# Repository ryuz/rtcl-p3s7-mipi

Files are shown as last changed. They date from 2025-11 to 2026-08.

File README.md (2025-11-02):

English version: [README_en.md](README_en.md)

# グローバルシャッターMIPI高速度カメラ(PYTHON300 + Spartan7)

## 概要

[こちら](https://rtc-lab.com/products/rtcl-cam-p3s7-mipi/)で紹介しておりますグローバルシャッターMIPI高速度カメラの KiCAD による設計データです。

オンセミコンダクター社 [PYTHON300イメージセンサー](https://www.onsemi.jp/products/sensors/image-sensors/python300) と AMD(Xilinx) の [Spartan7](https://www.amd.com/ja/products/adaptive-socs-and-fpgas/fpga/spartan-7.html) FPGA を用いた研究開発向けの小型のカメラモジュールです。

データシート上は VGA サイズながら 815fps の高速度撮影が可能と記載されているセンサーを利用しており、当方では [KV260](https://www.amd.com/ja/products/system-on-modules/kria/k26/kv260-vision-starter-kit.html) と [Zybo Z7](https://digilent.com/shop/zybo-z7-zynq-7000-arm-fpga-soc-development-board/) に接続して 320x320 サイズで 1000fps 撮像が出来ております。

カメラ外観写真

撮影動画なども[こちら](https://rtc-lab.com/products/rtcl-cam-p3s7-mipi/)で紹介しております。

## 回路図

回路図は以下です。

- [イメージセンサー子基板](sensor_python300/sensor_python300.pdf)
- [FPGA親基板](mipi_spartan7/mipi_spartan7.pdf)

## 基板販売

当方で製造したものを[BOOTH](https://rtc-lab.booth.pm/)にて販売中です。

- [モノクロ版](https://rtc-lab.booth.pm/items/7427869)
- [カラー版](https://rtc-lab.booth.pm/items/7428802)

## 関連ソフトウェア

現時点では、KV260 に独自仕様でデータを送るプロジェクトがあります。

- [Spartan-7 のデザイン](https://github.com/ryuz/rtcl-designs/tree/main/projects/rtcl_p3s7_mipi/rtcl_p3s7_mipi)
- [KV260 の デザイン](https://github.com/ryuz/rtcl-designs/tree/main/projects/kv260/kv260_rtcl_p3s7_hs)
- [ZYBO の デザイン](https://github.com/ryuz/rtcl-designs/tree/main/projects/zybo_z7/zybo_z7_rtcl_p3s7_hs)

## リポジトリ構成

| ディレクトリ |  説明 |
|:---|:---|
| mipi_spartan7 | Spartan7 FPGA の載った親基板のプロジェクト |
| sensor_python300 | PYTHON300 イメージセンサーの載った子基板のプロジェクト |
| sensor_mipi | 親子基板を共取り製造用に結合したプロジェクト |

## 免責事項

本設計データは、研究開発用の試作実験に用するものであり、利用に際して発生した如何なる損害も作者は補償いたしませんので予めご了承ください。

## ライセンス(License)

本設計データは、[クリエイティブ・コモンズ 表示-非営利 4.0 国際 ライセンス](https://creativecommons.org/licenses/by-nc/4.0/deed.ja)の下で提供されています。

製造した本基板の無断での販売や配布を行わない限りは、趣味や研究開発用途でご自由にお使いいただく事が出来ます。

また、商用に製造販売を希望される場合は、別途ライセンス契約を作者までご相談ください。[お問い合わせフォーム](https://rtc-lab.com/contact/)などからお問い合わせ頂けます。

## 作者情報

渕上 竜司(Ryuji Fuchikami)
[リアルタイムコンピューティング研究所](https://rtc-lab.com/)

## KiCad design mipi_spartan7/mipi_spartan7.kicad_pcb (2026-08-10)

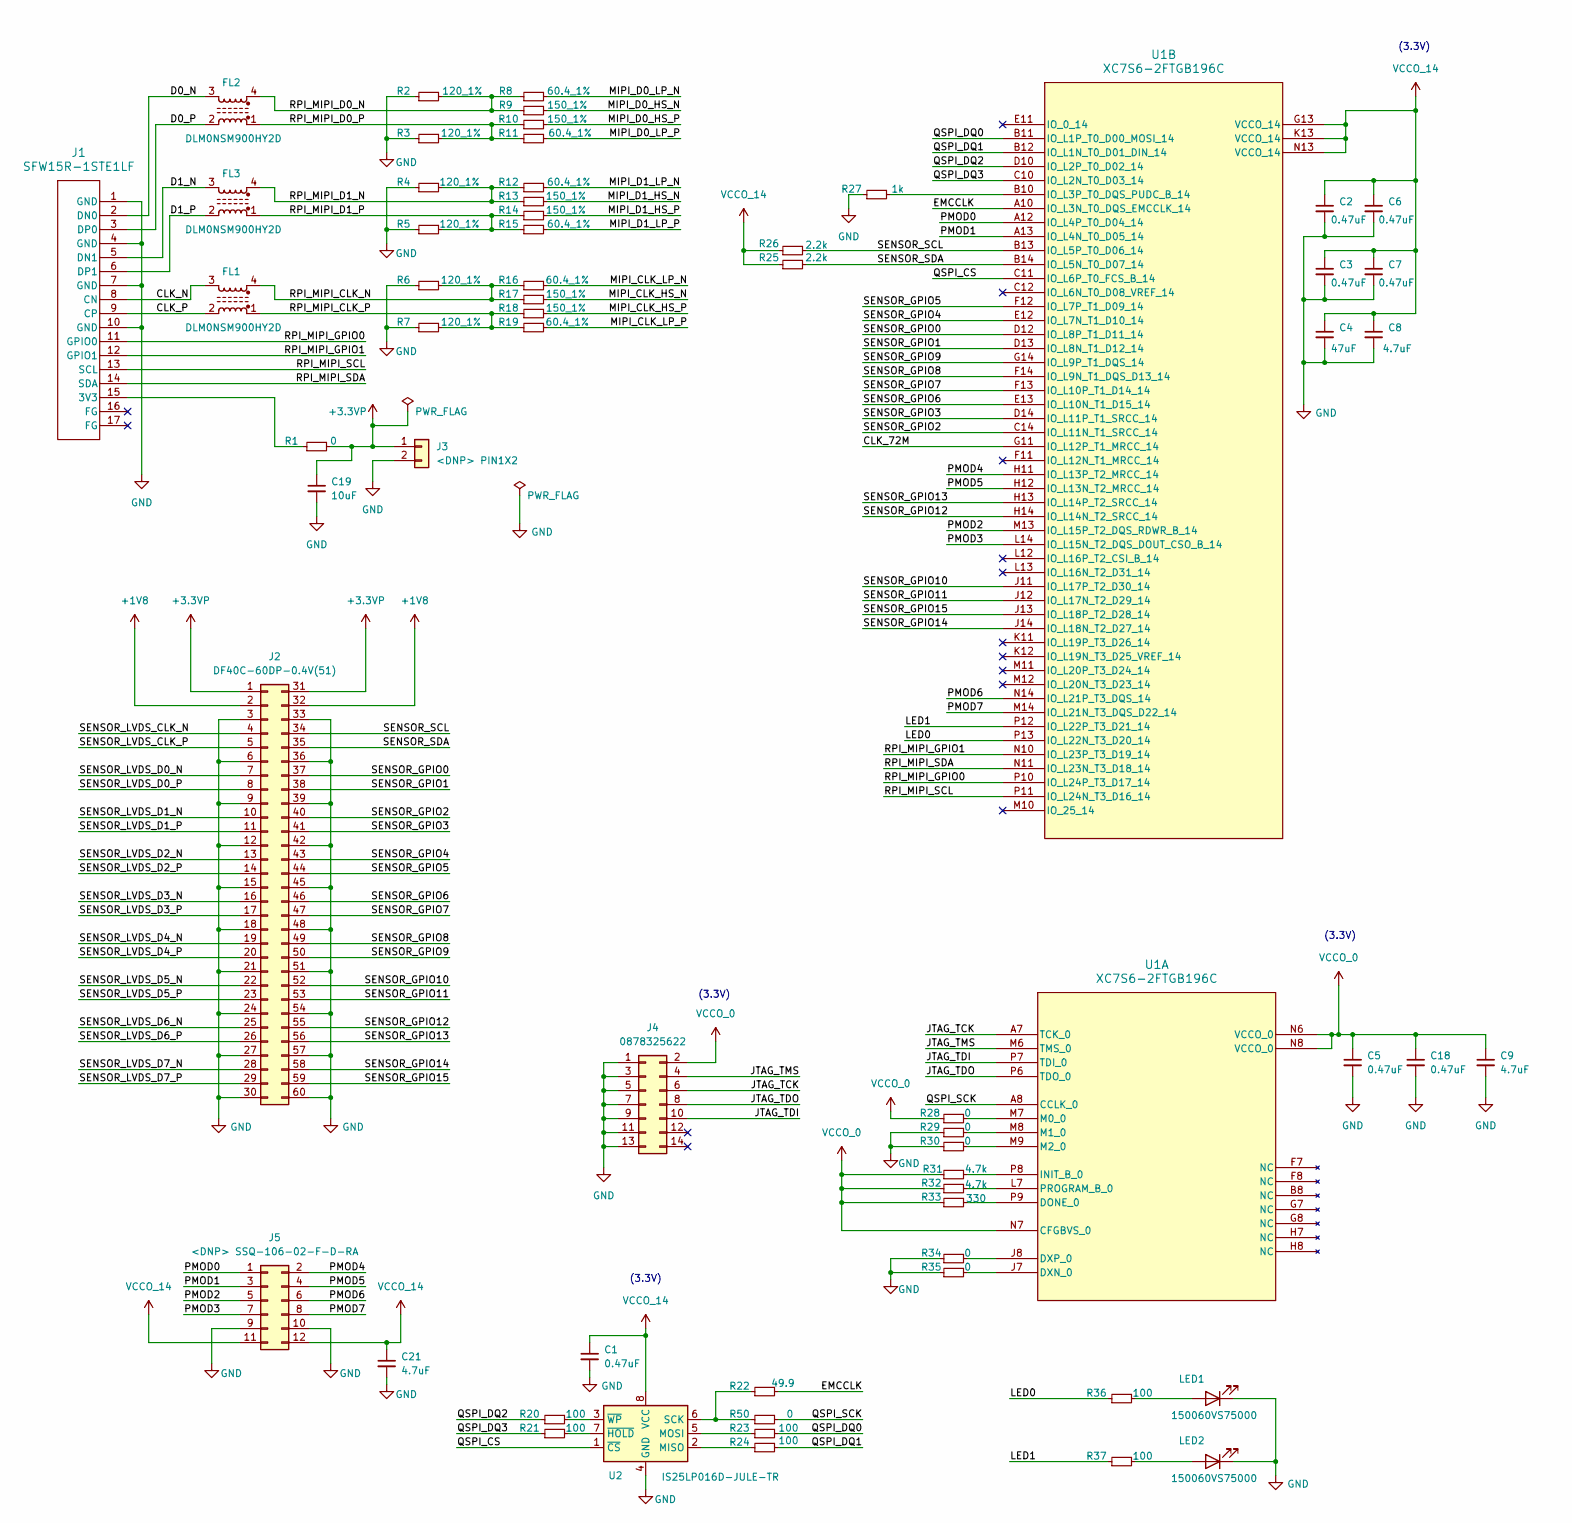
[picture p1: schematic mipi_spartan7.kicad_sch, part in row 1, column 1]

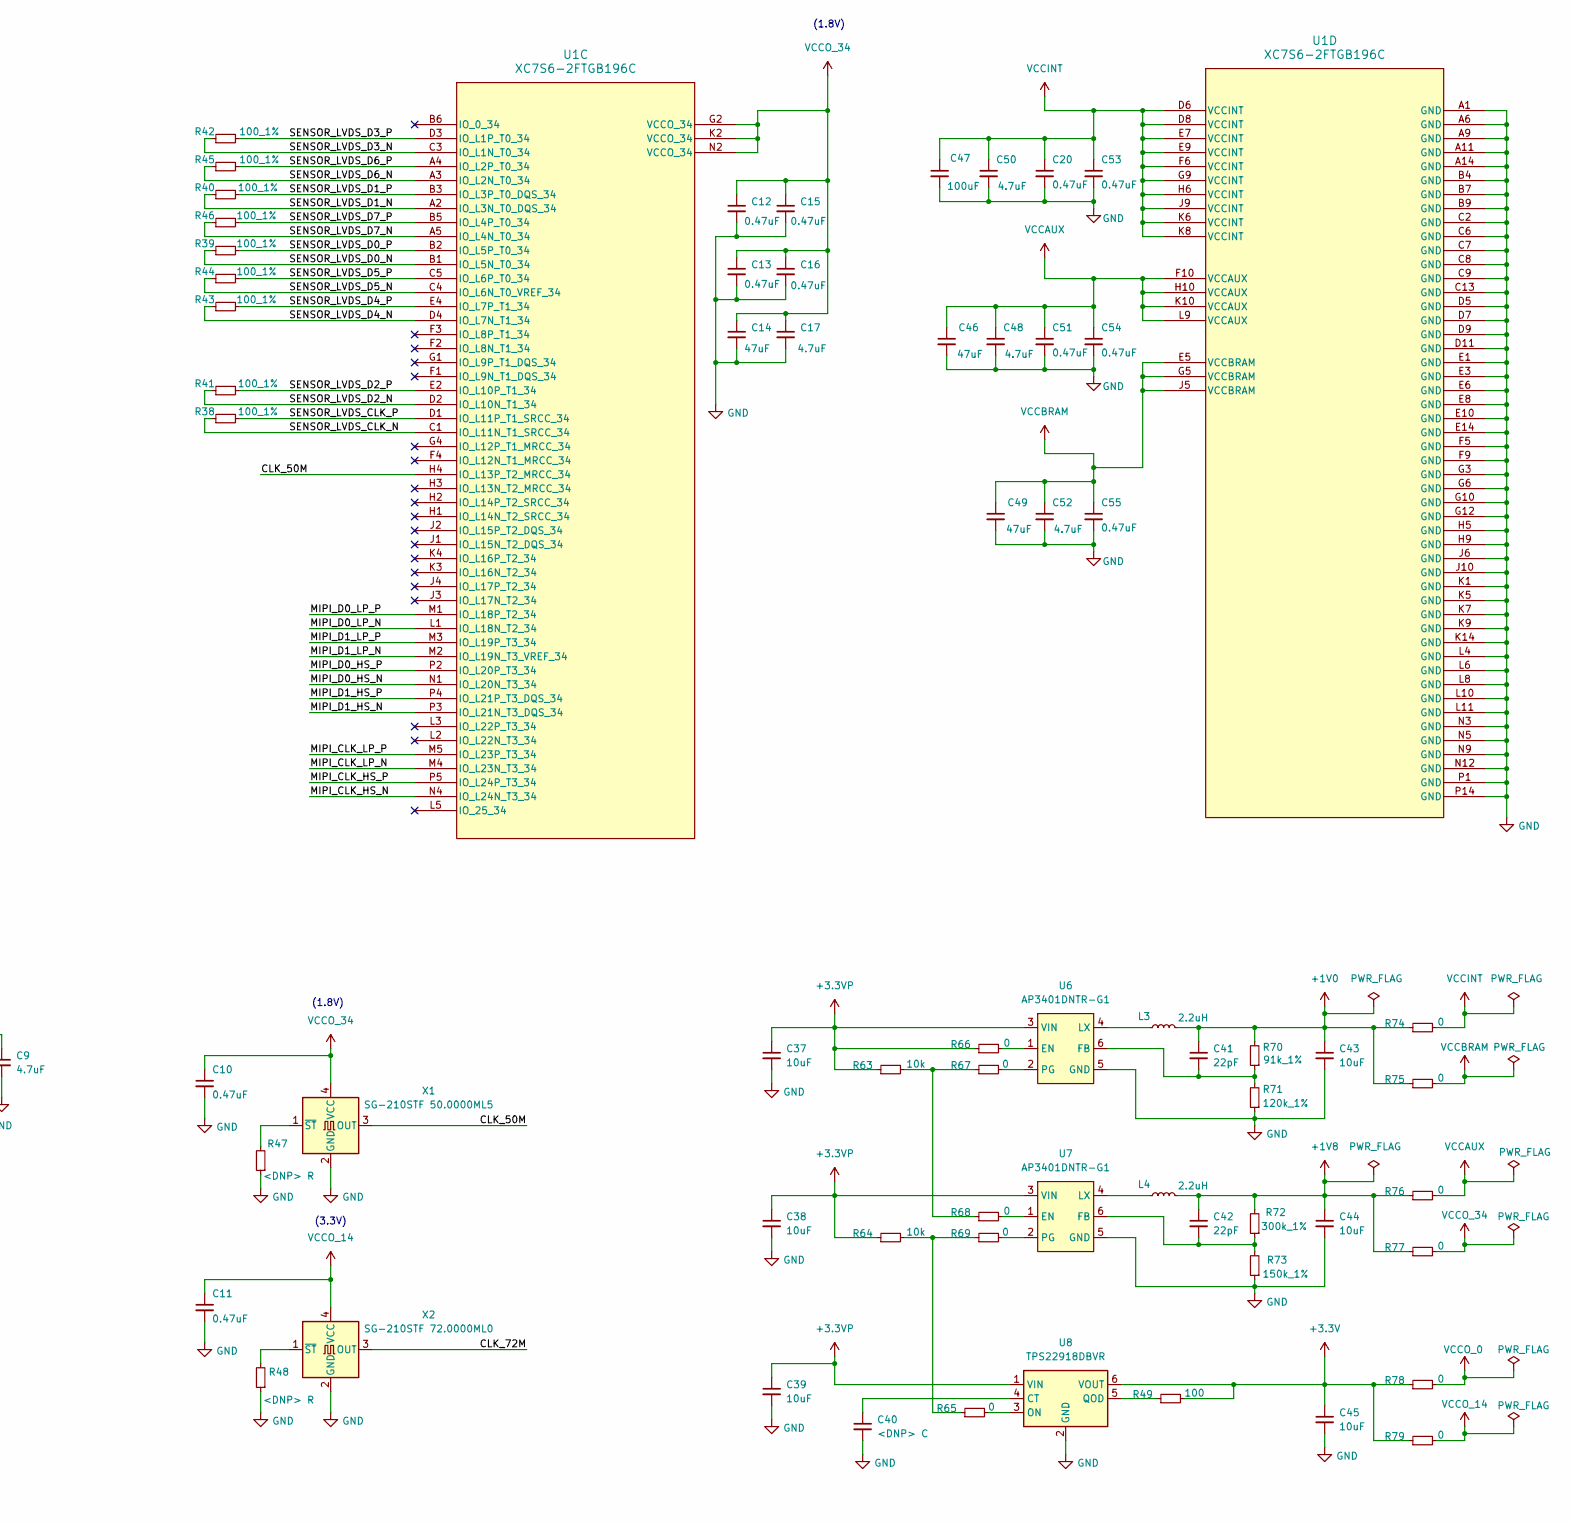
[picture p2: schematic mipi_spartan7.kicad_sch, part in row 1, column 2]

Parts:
C1, C2, C3, C5, C6, C7, C10, C11, C12, C13, C15, C16, C18, C20, C51, C53, C54, C55: 0.47uF; C_0402_1005Metric
C4, C14, C46, C49: 47uF; C_0603_1608Metric
C8, C9, C17, C21, C48, C50, C52: 4.7uF; C_0402_1005Metric
C19, C37, C38, C39, C43, C44, C45: 10uF; C_0603_1608Metric
C40: <DNP> C; L_0402_1005Metric
C41, C42: 22pF; L_0402_1005Metric
C47: 100uF; C_1206_3216Metric
FL1, FL2, FL3: DLM0NSM900HY2D; JLC C1857796
J1: SFW15R-1STE1LF
J2: DF40C-60DP-0.4V(51); DF40C-60DP-0.4V51
J3: <DNP> PIN1X2; PH_01x02_2.54mm_NoSilk
J4: 0878325622; 878325622; JLC C17275712
J5: <DNP> SSQ-106-02-F-D-RA; PH_02x06_2.54mm
L3, L4: 2.2uH; L_1008_2520Metric; JLC C576403
LED1, LED2: 150060VS75000; LED_0603_1608Metric
R1, R28, R29, R30, R34, R35, R50, R65, R66, R67, R68, R69, R74, R75, R76, R77, R78, R79: 0; R_0402_1005Metric
R2, R3, R4, R5, R6, R7: 120_1%; R_0402_1005Metric
R8, R11, R12, R15, R16, R19: 60.4_1%; R_0402_1005Metric
R9, R10, R13, R14, R17, R18: 150_1%; R_0402_1005Metric
R20, R21, R23, R24, R36, R37, R49: 100; R_0402_1005Metric
R22: 49.9; R_0402_1005Metric
R25, R26: 2.2k; R_0402_1005Metric
R27: 1k; R_0402_1005Metric
R31, R32: 4.7k; R_0402_1005Metric
R33: 330; R_0402_1005Metric
R38, R39, R40, R41, R42, R43, R44, R45, R46: 100_1%; R_0402_1005Metric
R47, R48: <DNP> R; R_0402_1005Metric
R63, R64: 10k; R_0402_1005Metric
R70: 91k_1%; R_0402_1005Metric
R71: 120k_1%; R_0402_1005Metric
R72: 300k_1%; R_0402_1005Metric
R73: 150k_1%; R_0402_1005Metric
U1: XC7S6-2FTGB196C; FTGB196; JLC C1521961
U2: IS25LP016D-JULE-TR; JLC C2063555
U6, U7: AP3401DNTR-G1; Diodes_UDFN2020-6_Type-J; JLC C507877
U8: TPS22918DBVR; SOT-23-6; JLC C131941
X1: SG-210STF 50.0000ML5; SG-210STF; JLC C17669095
X2: SG-210STF 72.0000ML0; SG-210STF; JLC C17270014

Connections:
+1V0: C41.1, C43.1, L3.2, R70.2, R74.1, R75.1
+1V8: C42.1, C44.1, J2.2, J2.32, L4.2, R72.2, R76.1, R77.1
+3.3V: C45.1, R49.2, R78.1, R79.1, U8.6 (VOUT)
+3.3VP: C19.1, C37.1, C38.1, C39.1, J2.1, J2.31, J3.1, R1.2, R63.1, R64.1, R66.1, U6.3 (VIN), U7.3 (VIN), U8.1 (VIN)
/CLK_50M: U1.H4 (IO_L13P_T2_MRCC_34), X1.3 (OUT)
/CLK_72M: U1.G11 (IO_L12P_T1_MRCC_14), X2.3 (OUT)
/CLK_N: FL1.3, J1.8 (CN)
/CLK_P: FL1.2, J1.9 (CP)
/D0_N: FL2.3, J1.2 (DN0)
/D0_P: FL2.2, J1.3 (DP0)
/D1_N: FL3.3, J1.5 (DN1)
/D1_P: FL3.2, J1.6 (DP1)
/EMCCLK: R22.2, U1.A10 (IO_L3N_T0_DQS_EMCCLK_14)
/JTAG_TCK: J4.6, U1.A7 (TCK_0)
/JTAG_TDI: J4.10, U1.P7 (TDI_0)
/JTAG_TDO: J4.8, U1.P6 (TDO_0)
/JTAG_TMS: J4.4, U1.M6 (TMS_0)
/LED0: R36.1, U1.P13 (IO_L22N_T3_D20_14)
/LED1: R37.1, U1.P12 (IO_L22P_T3_D21_14)
/MIPI_CLK_HS_N: R17.2, U1.N4 (IO_L24N_T3_34)
/MIPI_CLK_HS_P: R18.2, U1.P5 (IO_L24P_T3_34)
/MIPI_CLK_LP_N: R16.2, U1.M4 (IO_L23N_T3_34)
/MIPI_CLK_LP_P: R19.2, U1.M5 (IO_L23P_T3_34)
/MIPI_D0_HS_N: R9.2, U1.N1 (IO_L20N_T3_34)
/MIPI_D0_HS_P: R10.2, U1.P2 (IO_L20P_T3_34)
/MIPI_D0_LP_N: R8.2, U1.L1 (IO_L18N_T2_34)
/MIPI_D0_LP_P: R11.2, U1.M1 (IO_L18P_T2_34)
/MIPI_D1_HS_N: R13.2, U1.P3 (IO_L21N_T3_DQS_34)
/MIPI_D1_HS_P: R14.2, U1.P4 (IO_L21P_T3_DQS_34)
/MIPI_D1_LP_N: R12.2, U1.M2 (IO_L19N_T3_VREF_34)
/MIPI_D1_LP_P: R15.2, U1.M3 (IO_L19P_T3_34)
/PMOD0: J5.1, U1.A12 (IO_L4P_T0_D04_14)
/PMOD1: J5.3, U1.A13 (IO_L4N_T0_D05_14)
/PMOD2: J5.5, U1.M13 (IO_L15P_T2_DQS_RDWR_B_14)
/PMOD3: J5.7, U1.L14 (IO_L15N_T2_DQS_DOUT_CSO_B_14)
/PMOD4: J5.2, U1.H11 (IO_L13P_T2_MRCC_14)
/PMOD5: J5.4, U1.H12 (IO_L13N_T2_MRCC_14)
/PMOD6: J5.6, U1.N14 (IO_L21P_T3_DQS_14)
/PMOD7: J5.8, U1.M14 (IO_L21N_T3_DQS_D22_14)
/QSPI_CS: U1.C11 (IO_L6P_T0_FCS_B_14), U2.1 (~CS)
/QSPI_DQ0: R23.2, U1.B11 (IO_L1P_T0_D00_MOSI_14)
/QSPI_DQ1: R24.2, U1.B12 (IO_L1N_T0_D01_DIN_14)
/QSPI_DQ2: R20.1, U1.D10 (IO_L2P_T0_D02_14)
/QSPI_DQ3: R21.1, U1.C10 (IO_L2N_T0_D03_14)
/QSPI_SCK: R50.2, U1.A8 (CCLK_0)
/RPI_MIPI_CLK_N: FL1.4, R6.2, R16.1, R17.1
/RPI_MIPI_CLK_P: FL1.1, R7.2, R18.1, R19.1
/RPI_MIPI_D0_N: FL2.4, R2.2, R8.1, R9.1
/RPI_MIPI_D0_P: FL2.1, R3.2, R10.1, R11.1
/RPI_MIPI_D1_N: FL3.4, R4.2, R12.1, R13.1
/RPI_MIPI_D1_P: FL3.1, R5.2, R14.1, R15.1
/RPI_MIPI_GPIO0: J1.11 (GPIO0), U1.P10 (IO_L24P_T3_D17_14)
/RPI_MIPI_GPIO1: J1.12 (GPIO1), U1.N10 (IO_L23P_T3_D19_14)
/RPI_MIPI_SCL: J1.13 (SCL), U1.P11 (IO_L24N_T3_D16_14)
/RPI_MIPI_SDA: J1.14 (SDA), U1.N11 (IO_L23N_T3_D18_14)
/SENSOR_GPIO0: J2.37, U1.D12 (IO_L8P_T1_D11_14)
/SENSOR_GPIO1: J2.38, U1.D13 (IO_L8N_T1_D12_14)
/SENSOR_GPIO2: J2.40, U1.C14 (IO_L11N_T1_SRCC_14)
/SENSOR_GPIO3: J2.41, U1.D14 (IO_L11P_T1_SRCC_14)
/SENSOR_GPIO4: J2.43, U1.E12 (IO_L7N_T1_D10_14)
/SENSOR_GPIO5: J2.44, U1.F12 (IO_L7P_T1_D09_14)
/SENSOR_GPIO6: J2.46, U1.E13 (IO_L10N_T1_D15_14)
/SENSOR_GPIO7: J2.47, U1.F13 (IO_L10P_T1_D14_14)
/SENSOR_GPIO8: J2.49, U1.F14 (IO_L9N_T1_DQS_D13_14)
/SENSOR_GPIO9: J2.50, U1.G14 (IO_L9P_T1_DQS_14)
/SENSOR_GPIO10: J2.52, U1.J11 (IO_L17P_T2_D30_14)
/SENSOR_GPIO11: J2.53, U1.J12 (IO_L17N_T2_D29_14)
/SENSOR_GPIO12: J2.55, U1.H14 (IO_L14N_T2_SRCC_14)
/SENSOR_GPIO13: J2.56, U1.H13 (IO_L14P_T2_SRCC_14)
/SENSOR_GPIO14: J2.58, U1.J14 (IO_L18N_T2_D27_14)
/SENSOR_GPIO15: J2.59, U1.J13 (IO_L18P_T2_D28_14)
/SENSOR_LVDS_CLK_N: J2.4, R38.1, U1.C1 (IO_L11N_T1_SRCC_34)
/SENSOR_LVDS_CLK_P: J2.5, R38.2, U1.D1 (IO_L11P_T1_SRCC_34)
/SENSOR_LVDS_D0_N: J2.7, R39.1, U1.B1 (IO_L5N_T0_34)
/SENSOR_LVDS_D0_P: J2.8, R39.2, U1.B2 (IO_L5P_T0_34)
/SENSOR_LVDS_D1_N: J2.10, R40.1, U1.A2 (IO_L3N_T0_DQS_34)
/SENSOR_LVDS_D1_P: J2.11, R40.2, U1.B3 (IO_L3P_T0_DQS_34)
/SENSOR_LVDS_D2_N: J2.13, R41.1, U1.D2 (IO_L10N_T1_34)
/SENSOR_LVDS_D2_P: J2.14, R41.2, U1.E2 (IO_L10P_T1_34)
/SENSOR_LVDS_D3_N: J2.16, R42.1, U1.C3 (IO_L1N_T0_34)
/SENSOR_LVDS_D3_P: J2.17, R42.2, U1.D3 (IO_L1P_T0_34)
/SENSOR_LVDS_D4_N: J2.19, R43.1, U1.D4 (IO_L7N_T1_34)
/SENSOR_LVDS_D4_P: J2.20, R43.2, U1.E4 (IO_L7P_T1_34)
/SENSOR_LVDS_D5_N: J2.22, R44.1, U1.C4 (IO_L6N_T0_VREF_34)
/SENSOR_LVDS_D5_P: J2.23, R44.2, U1.C5 (IO_L6P_T0_34)
/SENSOR_LVDS_D6_N: J2.25, R45.1, U1.A3 (IO_L2N_T0_34)
/SENSOR_LVDS_D6_P: J2.26, R45.2, U1.A4 (IO_L2P_T0_34)
/SENSOR_LVDS_D7_N: J2.28, R46.1, U1.A5 (IO_L4N_T0_34)
/SENSOR_LVDS_D7_P: J2.29, R46.2, U1.B5 (IO_L4P_T0_34)
/SENSOR_SCL: J2.34, R26.2, U1.B13 (IO_L5P_T0_D06_14)
/SENSOR_SDA: J2.35, R25.2, U1.B14 (IO_L5N_T0_D07_14)
GND: C1.2, C2.2, C3.2, C4.2, C5.2, C6.2, C7.2, C8.2, C9.2, C10.2, C11.2, C12.2, C13.2, C14.2, C15.2, C16.2, C17.2, C18.2, C19.2, C20.2, C21.2, C37.2, C38.2, C39.2, C40.2, C43.2, C44.2, C45.2, C46.2, C47.2, C48.2, C49.2, C50.2, C51.2, C52.2, C53.2, C54.2, C55.2, J1.1 (GND), J1.4 (GND), J1.7 (GND), J1.10 (GND), J2.3, J2.6, J2.9, J2.12, J2.15, J2.18, J2.21, J2.24, J2.27, J2.30, J2.33, J2.36, J2.39, J2.42, J2.45, J2.48, J2.51, J2.54, J2.57, J2.60, J3.2, J4.1, J4.3, J4.5, J4.7, J4.9, J4.11, J4.13, J5.9, J5.10, LED1.1 (K), LED2.1 (K), R2.1, R3.1, R4.1, R5.1, R6.1, R7.1, R27.1, R29.1, R30.1, R34.1, R35.1, R47.1, R48.1, R71.1, R73.1, U1.A1 (GND), U1.A6 (GND), U1.A9 (GND), U1.A11 (GND), U1.A14 (GND), U1.B4 (GND), U1.B7 (GND), U1.B9 (GND), U1.C2 (GND), U1.C6 (GND), U1.C7 (GND), U1.C8 (GND), U1.C9 (GND), U1.C13 (GND), U1.D5 (GND), U1.D7 (GND), U1.D9 (GND), U1.D11 (GND), U1.E1 (GND), U1.E3 (GND), U1.E6 (GND), U1.E8 (GND), U1.E10 (GND), U1.E14 (GND), U1.F5 (GND), U1.F9 (GND), U1.G3 (GND), U1.G6 (GND), U1.G10 (GND), U1.G12 (GND), U1.H5 (GND), U1.H9 (GND), U1.J6 (GND), U1.J10 (GND), U1.K1 (GND), U1.K5 (GND), U1.K7 (GND), U1.K9 (GND), U1.K14 (GND), U1.L4 (GND), U1.L6 (GND), U1.L8 (GND), U1.L10 (GND), U1.L11 (GND), U1.N3 (GND), U1.N5 (GND), U1.N9 (GND), U1.N12 (GND), U1.P1 (GND), U1.P14 (GND), U2.4 (GND), U6.5 (GND), U7.5 (GND), U8.2 (GND), X1.2 (GND), X2.2 (GND)
unnamed: J1.15 (3V3), R1.1
unnamed: LED1.2 (A), R36.2
unnamed: LED2.2 (A), R37.2
unnamed: R63.2, R67.1, R68.1
unnamed: R64.2, R65.1, R69.1
unnamed: R33.2, U1.P9 (DONE_0)
unnamed: R35.2, U1.J7 (DXN_0)
unnamed: R34.2, U1.J8 (DXP_0)
unnamed: R31.2, U1.P8 (INIT_B_0)
unnamed: R28.2, U1.M7 (M0_0)
unnamed: R29.2, U1.M8 (M1_0)
unnamed: R30.2, U1.M9 (M2_0)
unnamed: R32.2, U1.L7 (PROGRAM_B_0)
unnamed: R27.2, U1.B10 (IO_L3P_T0_DQS_PUDC_B_14)
unnamed: R24.1, U2.2 (MISO)
unnamed: R23.1, U2.5 (MOSI)
unnamed: R22.1, R50.1, U2.6 (SCK)
unnamed: R21.2, U2.7 (~HOLD)
unnamed: R20.2, U2.3 (~WP)
unnamed: R66.2, U6.1 (EN)
unnamed: C41.2, R70.1, R71.2, U6.6 (FB)
unnamed: L3.1, U6.4 (LX)
unnamed: R67.2, U6.2 (PG)
unnamed: R68.2, U7.1 (EN)
unnamed: C42.2, R72.1, R73.2, U7.6 (FB)
unnamed: L4.1, U7.4 (LX)
unnamed: R69.2, U7.2 (PG)
unnamed: C40.1, U8.4 (CT)
unnamed: R65.2, U8.3 (ON)
unnamed: R49.1, U8.5 (QOD)
unnamed: R47.2, X1.1 (~ST)
unnamed: R48.2, X2.1 (~ST)
VCCAUX: C46.1, C48.1, C51.1, C54.1, R76.2, U1.F10 (VCCAUX), U1.H10 (VCCAUX), U1.K10 (VCCAUX), U1.L9 (VCCAUX)
VCCBRAM: C49.1, C52.1, C55.1, R75.2, U1.E5 (VCCBRAM), U1.G5 (VCCBRAM), U1.J5 (VCCBRAM)
VCCINT: C20.1, C47.1, C50.1, C53.1, R74.2, U1.D6 (VCCINT), U1.D8 (VCCINT), U1.E7 (VCCINT), U1.E9 (VCCINT), U1.F6 (VCCINT), U1.G9 (VCCINT), U1.H6 (VCCINT), U1.J9 (VCCINT), U1.K6 (VCCINT), U1.K8 (VCCINT)
VCCO_0: C5.1, C9.1, C18.1, J4.2, R28.1, R31.1, R32.1, R33.1, R78.2, U1.N6 (VCCO_0), U1.N7 (CFGBVS_0), U1.N8 (VCCO_0)
VCCO_14: C1.1, C2.1, C3.1, C4.1, C6.1, C7.1, C8.1, C11.1, C21.1, J5.11, J5.12, R25.1, R26.1, R79.2, U1.G13 (VCCO_14), U1.K13 (VCCO_14), U1.N13 (VCCO_14), U2.8 (VCC), X2.4 (VCC)
VCCO_34: C10.1, C12.1, C13.1, C14.1, C15.1, C16.1, C17.1, R77.2, U1.G2 (VCCO_34), U1.K2 (VCCO_34), U1.N2 (VCCO_34), X1.4 (VCC)

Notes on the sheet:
(1.8V)
(3.3V)

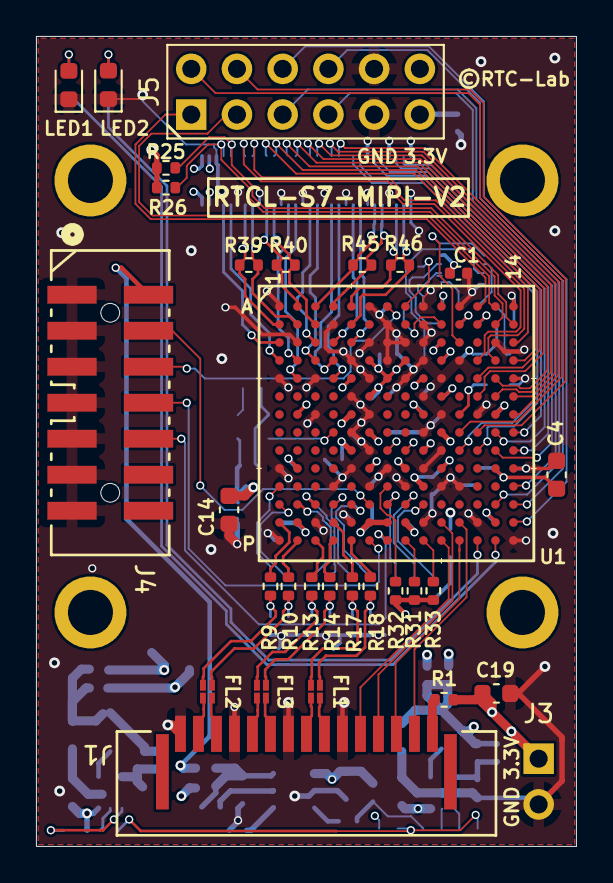
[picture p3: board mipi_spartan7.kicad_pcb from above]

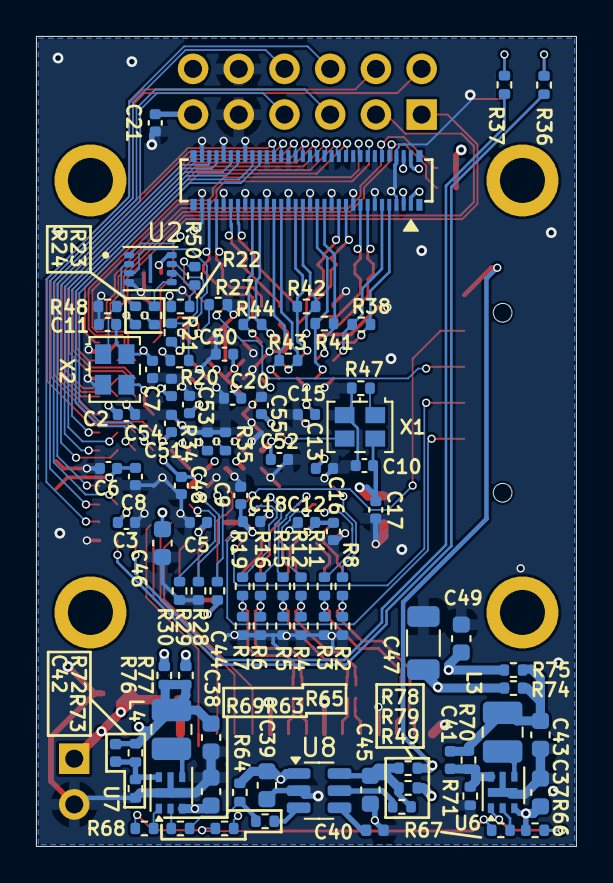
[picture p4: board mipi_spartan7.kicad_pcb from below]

Board: 4 copper layers, 30.0 x 45.0 mm, 126 parts (96 on the bottom side), 130 nets.

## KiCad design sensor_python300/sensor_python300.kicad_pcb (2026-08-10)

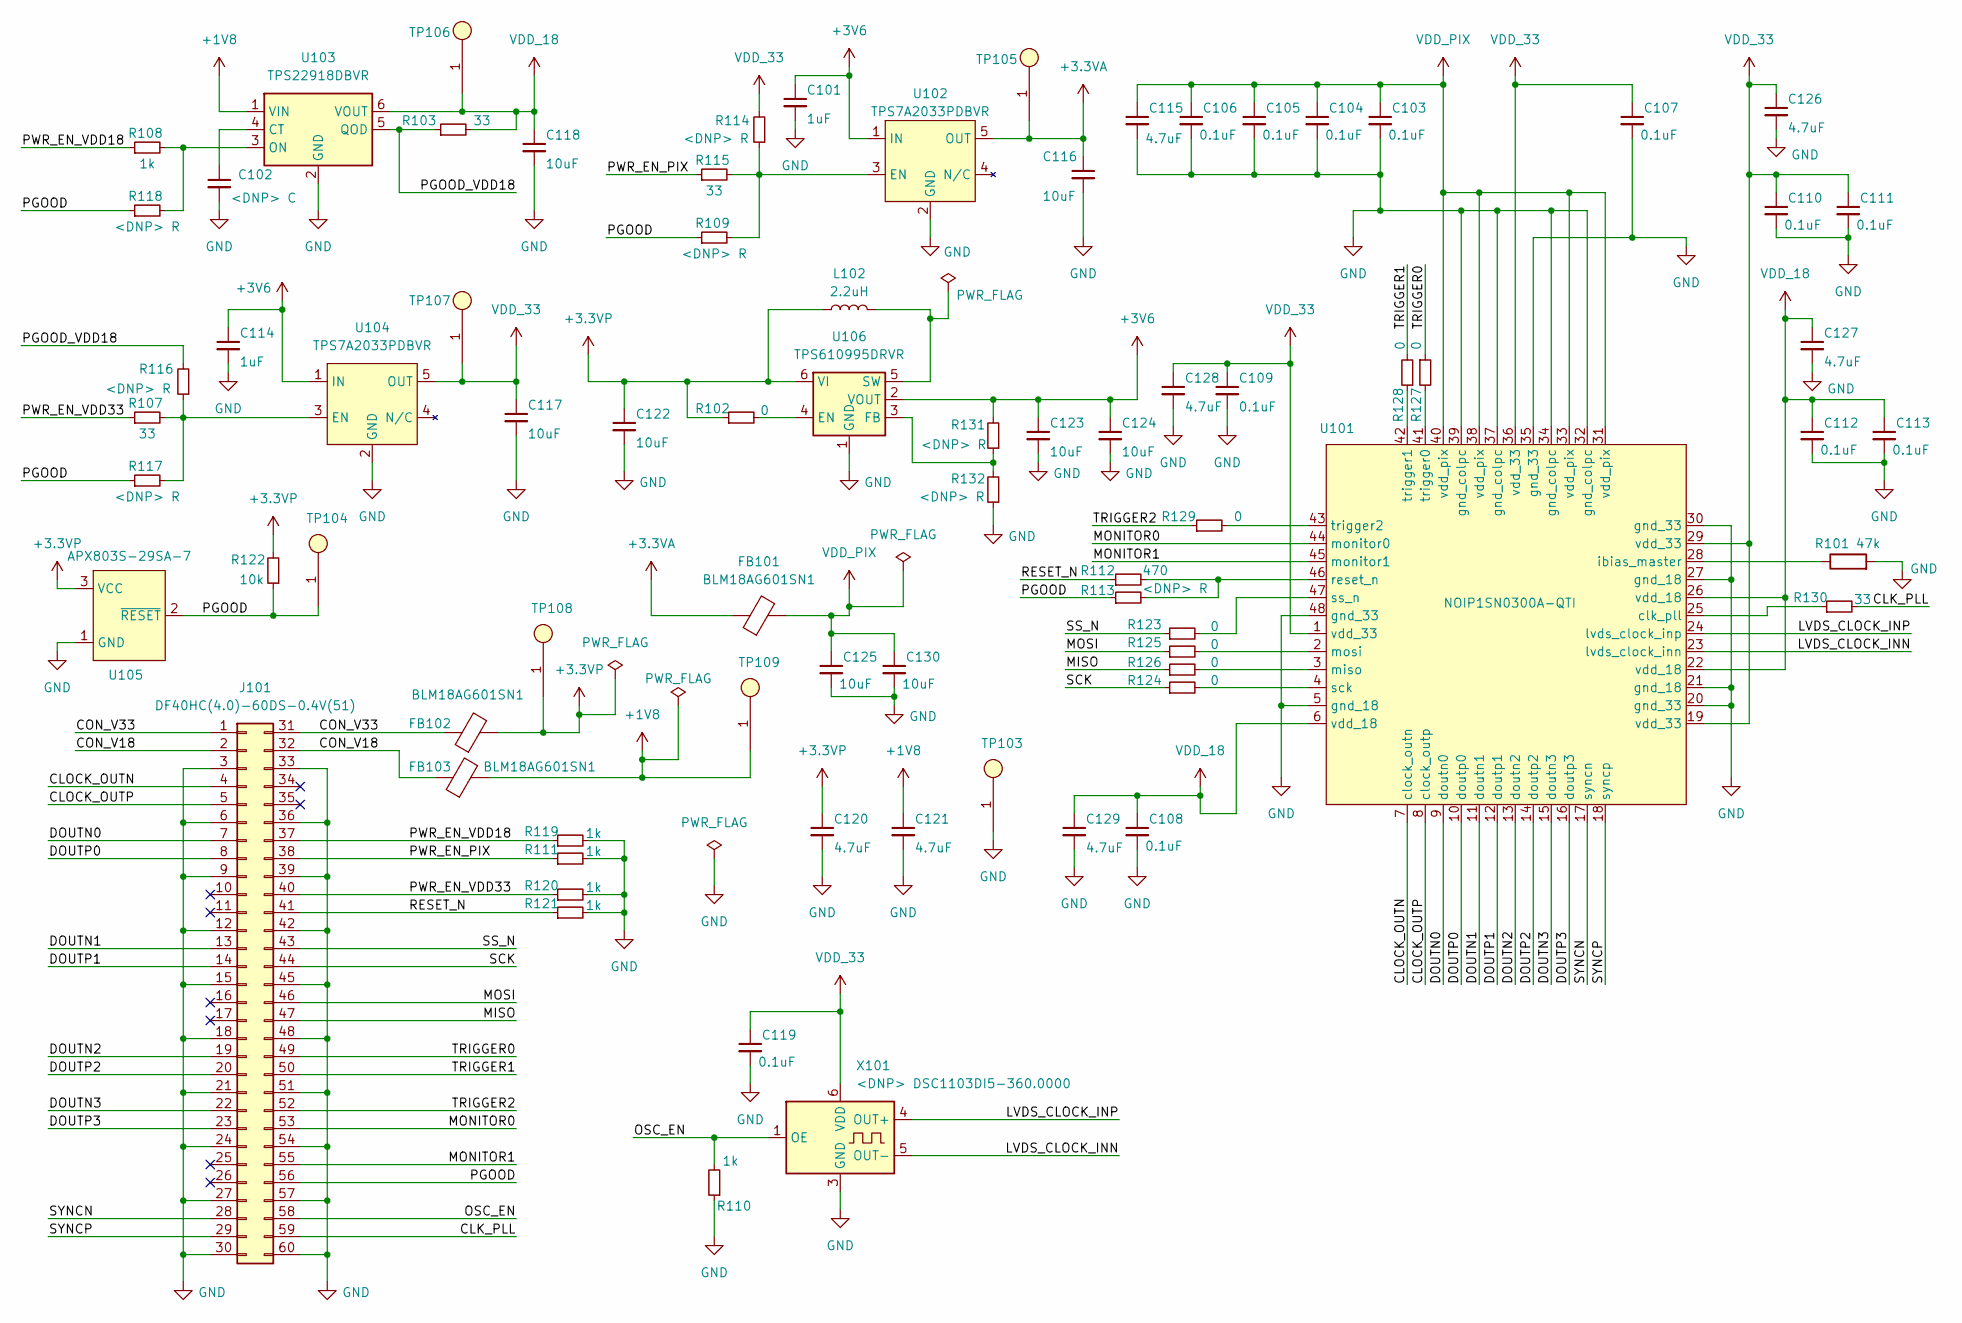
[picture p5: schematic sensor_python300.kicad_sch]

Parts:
C101, C114: 1uF; C_0402_1005Metric
C102: <DNP> C; C_0402_1005Metric
C103, C104, C105, C106, C107, C108, C109, C110, C111, C112, C113, C119: 0.1uF; C_0402_1005Metric
C115, C120, C121, C126, C127, C128, C129: 4.7uF; C_0402_1005Metric
C116, C117, C118: 10uF; C_0402_1005Metric
C122, C123, C124, C125, C130: 10uF; C_0603_1608Metric
FB101, FB102, FB103: BLM18AG601SN1; L_0603_1608Metric
J101: DF40HC(4.0)-60DS-0.4V(51); DF40HC4.0-60DS-0.4V51
L102: 2.2uH; L_1008_2520Metric
R101: 47k; R_0402_1005Metric
R102, R123, R124, R125, R126, R127, R128, R129: 0; R_0402_1005Metric
R103, R107, R115, R130: 33; R_0402_1005Metric
R108, R110, R111, R119, R120, R121: 1k; R_0402_1005Metric
R109, R113, R114, R116, R117, R118, R131, R132: <DNP> R; R_0402_1005Metric
R112: 470; R_0402_1005Metric
R122: 10k; R_0402_1005Metric
TP103, TP104, TP105, TP106, TP107, TP108, TP109: TestPin
U101: NOIP1SN0300A-QTI; NOIP1SN1300A
U102, U104: TPS7A2033PDBVR; SOT-23-5
U103: TPS22918DBVR; SOT-23-6
U105: APX803S-29SA-7; SOT-23-3
U106: TPS610995DRVR; WSON-6-1EP_2x2mm_P0.65mm_EP1x1.6mm
X101: <DNP> DSC1103DI5-360.0000; Oscillator_SMD_SiTime_PQFD-6L_3.2x2.5mm

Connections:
+1V8: C121.1, FB103.2, TP109.1, U103.1 (VIN)
+3.3VA: C116.1, FB101.1, TP105.1, U102.5 (OUT)
+3.3VP: C120.1, C122.1, FB102.2, L102.1, R102.1, R122.2, TP108.1, U105.3 (VCC), U106.6 (VI)
+3V6: C101.1, C114.1, C123.1, C124.1, R131.2, U102.1 (IN), U104.1 (IN), U106.2 (VOUT)
/CLK_PLL: J101.59, R130.2
/CLOCK_OUTN: J101.4, U101.7 (clock_outn)
/CLOCK_OUTP: J101.5, U101.8 (clock_outp)
/CON_V18: FB103.1, J101.2, J101.32
/CON_V33: FB102.1, J101.1, J101.31
/DOUTN0: J101.7, U101.9 (doutn0)
/DOUTN1: J101.13, U101.11 (doutn1)
/DOUTN2: J101.19, U101.13 (doutn2)
/DOUTN3: J101.22, U101.15 (doutn3)
/DOUTP0: J101.8, U101.10 (doutp0)
/DOUTP1: J101.14, U101.12 (doutp1)
/DOUTP2: J101.20, U101.14 (doutp2)
/DOUTP3: J101.23, U101.16 (doutp3)
/LVDS_CLOCK_INN: U101.23 (lvds_clock_inn), X101.5 (OUT-)
/LVDS_CLOCK_INP: U101.24 (lvds_clock_inp), X101.4 (OUT+)
/MISO: J101.47, R126.1
/MONITOR0: J101.53, U101.44 (monitor0)
/MONITOR1: J101.55, U101.45 (monitor1)
/MOSI: J101.46, R125.1
/OSC_EN: J101.58, R110.2, X101.1 (OE)
/PGOOD: J101.56, R109.1, R113.1, R117.1, R118.1, R122.1, TP104.1, U105.2 (~RESET)
/PGOOD_VDD18: R103.1, R116.2, U103.5 (QOD)
/PWR_EN_PIX: J101.38, R111.1, R115.1
/PWR_EN_VDD18: J101.37, R108.1, R119.1
/PWR_EN_VDD33: J101.40, R107.1, R120.1
/RESET_N: J101.41, R112.1, R121.1
/SCK: J101.44, R124.1
/SS_N: J101.43, R123.1
/SYNCN: J101.28, U101.17 (syncn)
/SYNCP: J101.29, U101.18 (syncp)
/TRIGGER0: J101.49, R127.1
/TRIGGER1: J101.50, R128.2
/TRIGGER2: J101.52, R129.1
GND: C101.2, C102.2, C103.2, C104.2, C105.2, C106.2, C107.2, C108.2, C109.2, C110.2, C111.2, C112.2, C113.2, C114.2, C115.2, C116.2, C117.2, C118.2, C119.2, C120.2, C121.2, C122.2, C123.2, C124.2, C125.2, C126.2, C127.2, C128.2, C129.2, C130.2, J101.3, J101.6, J101.9, J101.12, J101.15, J101.18, J101.21, J101.24, J101.27, J101.30, J101.33, J101.36, J101.39, J101.42, J101.45, J101.48, J101.51, J101.54, J101.57, J101.60, R101.2, R110.1, R111.2, R119.2, R120.2, R121.2, R132.1, TP103.1, U101.5 (gnd_18), U101.20 (gnd_33), U101.21 (gnd_18), U101.27 (gnd_18), U101.30 (gnd_33), U101.32 (gnd_colpc), U101.34 (gnd_colpc), U101.35 (gnd_33), U101.37 (gnd_colpc), U101.39 (gnd_colpc), U101.48 (gnd_33), U102.2 (GND), U103.2 (GND), U104.2 (GND), U105.1 (GND), U106.1 (GND), U106.7 (GND), X101.3 (GND)
unnamed: R130.1, U101.25 (clk_pll)
unnamed: R101.1, U101.28 (ibias_master)
unnamed: R126.2, U101.3 (miso)
unnamed: R125.2, U101.2 (mosi)
unnamed: R112.2, R113.2, U101.46 (reset_n)
unnamed: R124.2, U101.4 (sck)
unnamed: R123.2, U101.47 (ss_n)
unnamed: R127.2, U101.41 (trigger0)
unnamed: R128.1, U101.42 (trigger1)
unnamed: R129.2, U101.43 (trigger2)
unnamed: R109.2, R114.1, R115.2, U102.3 (EN)
unnamed: C102.1, U103.4 (CT)
unnamed: R108.2, R118.2, U103.3 (ON)
unnamed: R107.2, R116.1, R117.2, U104.3 (EN)
unnamed: R102.2, U106.4 (EN)
unnamed: R131.1, R132.2, U106.3 (FB)
unnamed: L102.2, U106.5 (SW)
VDD_18: C108.1, C112.1, C113.1, C118.1, C127.1, C129.1, R103.2, TP106.1, U101.6 (vdd_18), U101.22 (vdd_18), U101.26 (vdd_18), U103.6 (VOUT)
VDD_33: C107.1, C109.1, C110.1, C111.1, C117.1, C119.1, C126.1, C128.1, R114.2, TP107.1, U101.1 (vdd_33), U101.19 (vdd_33), U101.29 (vdd_33), U101.36 (vdd_33), U104.5 (OUT), X101.6 (VDD)
VDD_PIX: C103.1, C104.1, C105.1, C106.1, C115.1, C125.1, C130.1, FB101.2, U101.31 (vdd_pix), U101.33 (vdd_pix), U101.38 (vdd_pix), U101.40 (vdd_pix)

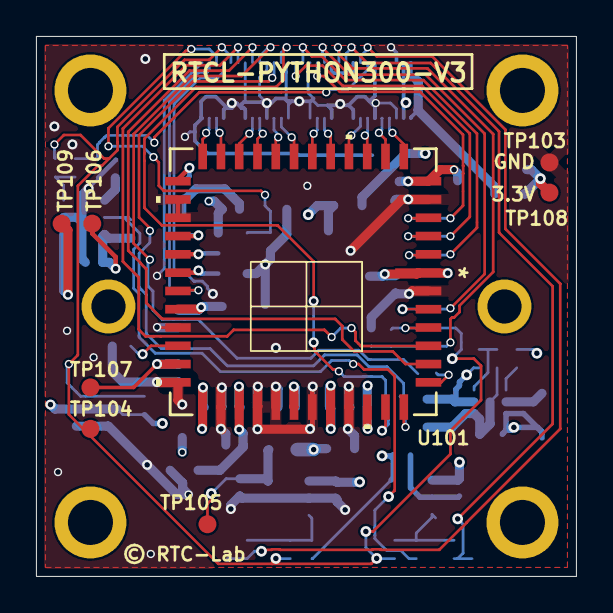
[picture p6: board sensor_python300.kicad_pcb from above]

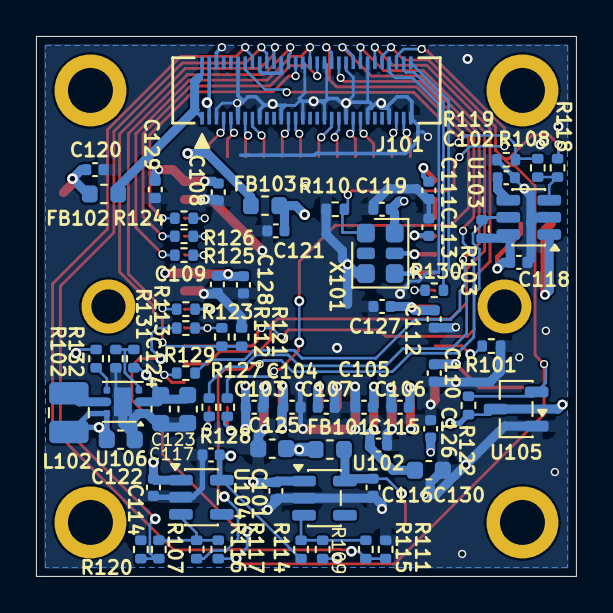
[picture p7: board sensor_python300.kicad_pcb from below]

Board: 4 copper layers, 30.0 x 30.0 mm, 78 parts (70 on the bottom side), 58 nets.

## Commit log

2025-11-02 Update design links in README and README_en for ZYBO to reflect current project status
2026-06-06 Update KiCad project files for sensor_python300 and mipi_spartan7: adjust active layer, visibility settings, and add default application options
    [sensor_python300.kicad_sch]
2026-06-06 コンデンサ追加
    [sensor_python300.kicad_sch]
2026-06-06 Update KiCad project files for sensor_python300
    - Changed active layer from 0 to 2 in sensor_python300.kicad_prl.
    - Modified selection filter settings to disable dimensions, footprints, graphics, keepouts, other items, pads, text, and zones.
    - Updated visible layers in sensor_python300.kicad_prl for better layer management.
    - Adjusted design rules in sensor_python300.kicad_pro:
    - Reduced minimum copper edge clearance from 0.5 to 0.2.
    - Increased minimum hole clearance from 0.25 to 0.28 and minimum hole-to-hole distance from 0.25 to 0.45.
    - Decreased minimum text height from 0.75 to 0.1 and thickness from 0.15 to 0.01.
    - Updated minimum through hole diameter from 0.2 to 0.3.
    - Reduc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
    [sensor_python300.kicad_pcb]
2026-06-06 Update schematic and project settings for sensor_python300
    - Modified selection filter in project settings to enable footprint and text visibility.
    - Updated visible layers configuration for better layer management.
    - Added new junctions and wires in the schematic to improve connectivity.
    - Introduced a new capacitor (C130) with appropriate properties and connections.
    - Replaced the existing GND symbol with a new instance for better clarity and organization.
    - Adjusted positions of several components for improved layout and readability.
    [sensor_python300.kicad_pcb, sensor_python300.kicad_sch]
2026-08-10 KiCAD 10.0 へ
    [mipi_spartan7.kicad_pcb, mipi_spartan7.kicad_sch, sensor_python300.kicad_pcb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]
2026-08-10 VIA径を JLCPCB仕様に
    [mipi_spartan7.kicad_pcb]

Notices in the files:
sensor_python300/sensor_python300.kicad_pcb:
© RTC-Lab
